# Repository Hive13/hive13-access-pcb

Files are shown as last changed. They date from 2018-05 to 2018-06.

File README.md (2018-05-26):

# hive13-access-pcb
KiCad files for the circuit board that controls doors.

## Board Design
This board is designed so that it can be sent to a fab house and done dual-layer, or milled with a CNC, single-sided, and done in the "jumper links" style.
This results in several constraints:
- The top-side PCB traces need to both be in a straight line and not cross over any top-side components.
- All surface-mount components need to be on the bottom layer.
- No vias under bottom-side components.
- Assume that there will be no bottom-side solder mask.  Take this into account when running traces under a bottom-side component.

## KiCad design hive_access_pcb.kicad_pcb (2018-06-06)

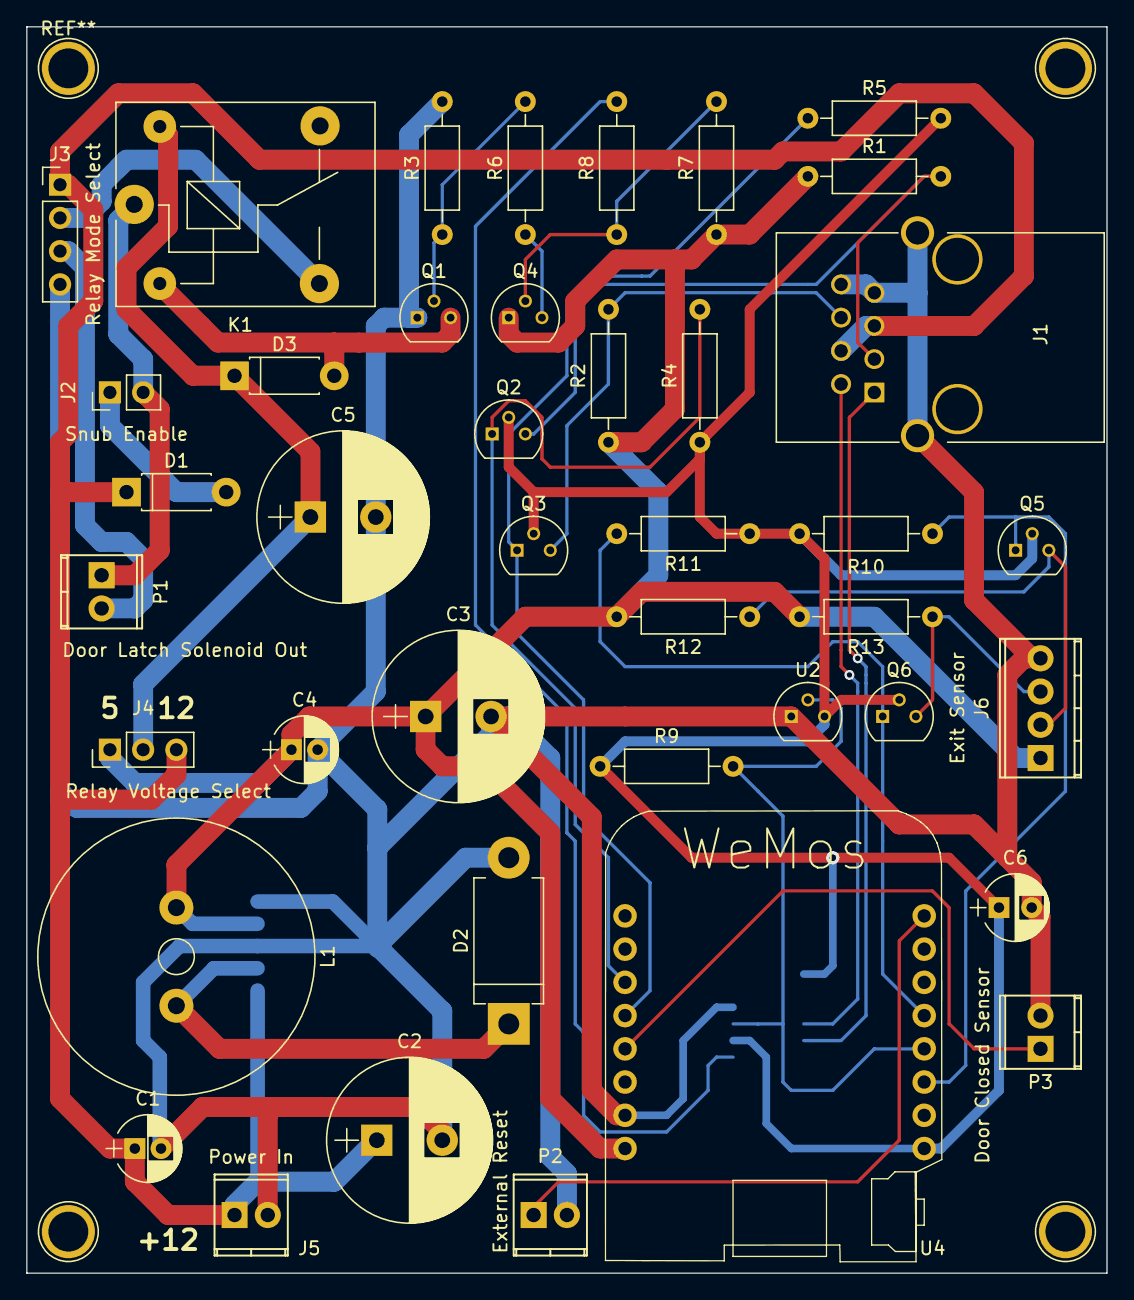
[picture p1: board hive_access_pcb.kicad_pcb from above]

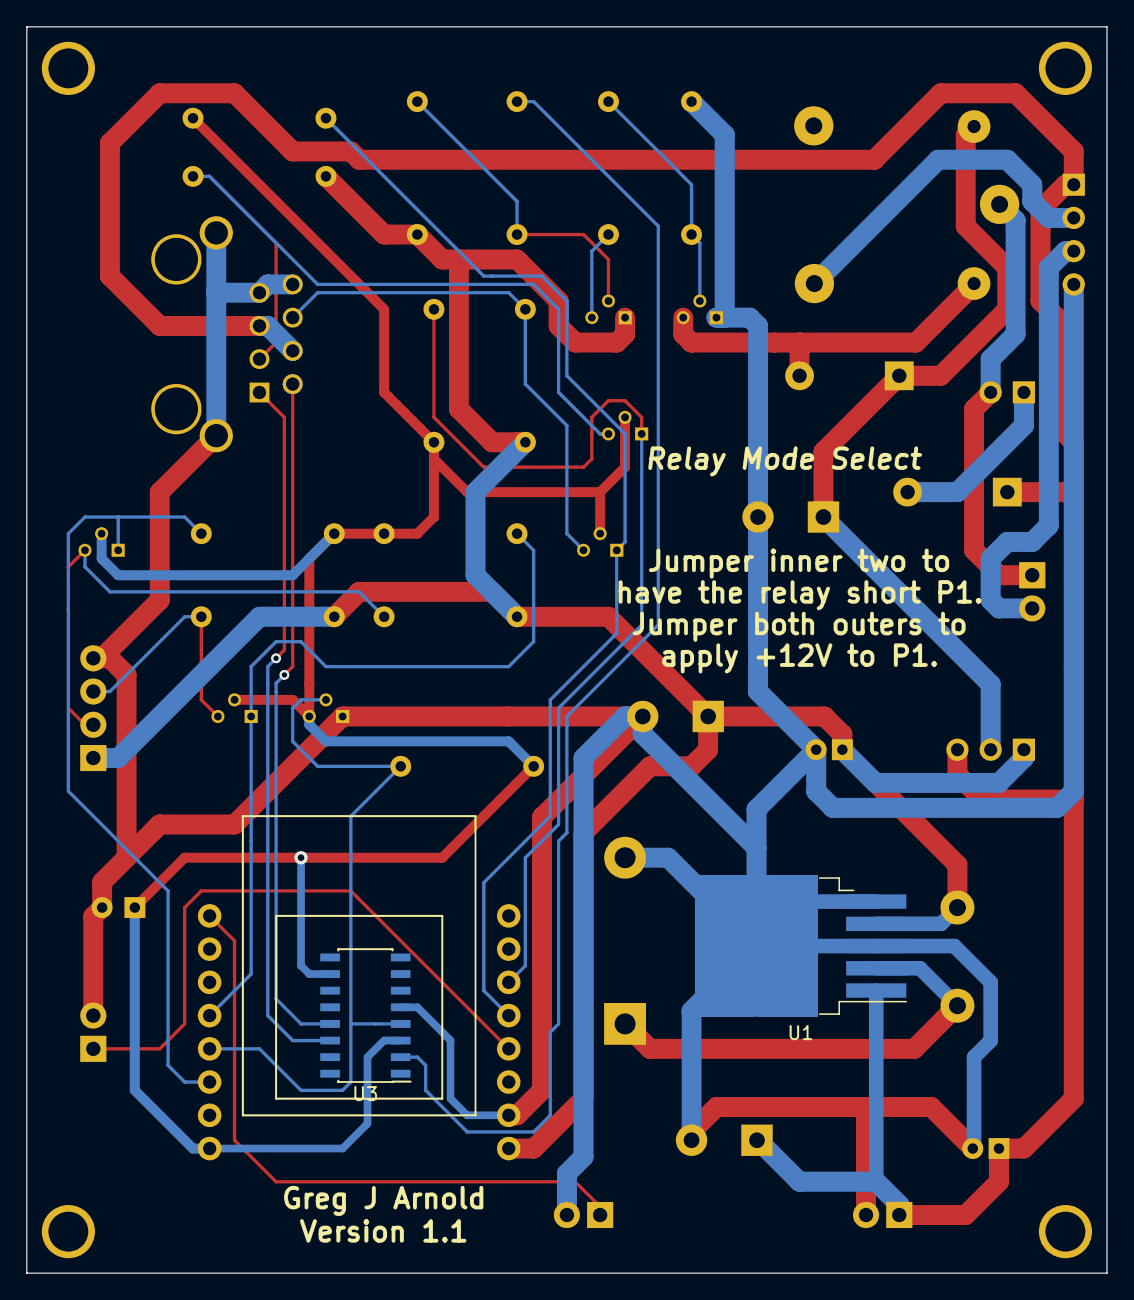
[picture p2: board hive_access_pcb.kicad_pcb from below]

Board: 2 copper layers, 82.6 x 95.2 mm, 43 parts (2 on the bottom side), 28 nets.

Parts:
C1, C4: 1MFD; CP_Radial_D5.0mm_P2.00mm
C2: 100MFD; CP_Radial_D12.5mm_P5.00mm
C3, C5: 1000MFD; CP_Radial_D13.0mm_P5.00mm
C6: 1MFD; CP_Radial_D5.0mm_P2.50mm
D1, D3: 1N4002; D_DO-41_SOD81_P7.62mm_Horizontal
D2: D_Schottky; D_DO-201AD_P12.70mm_Horizontal
J1: Door Reader; RJ45_SHIELD
J2: Snub Enable; Pin_Header_Straight_1x02_Pitch2.54mm
J3: Relay Mode Select; Pin_Header_Straight_1x04_Pitch2.54mm
J4: Relay Voltage Select; Pin_Header_Straight_1x03_Pitch2.54mm
J5: Power In; TerminalBlock_Pheonix_MPT-2.54mm_2pol
J6: Exit Sensor; TerminalBlock_Pheonix_MPT-2.54mm_4pol
K1: SANYOU_SRD_Form_C; Relay_SPDT_SANYOU_SRD_Series_Form_C
L1: L; L_Radial_D21.0mm_P7.5mm
P1: Door Latch Solenoid Out; TerminalBlock_Pheonix_MPT-2.54mm_2pol
P2: External Reset; TerminalBlock_Pheonix_MPT-2.54mm_2pol
P3: Door Closed Sensor; TerminalBlock_Pheonix_MPT-2.54mm_2pol
Q1: 2N2222; TO-92_Molded_Narrow
Q2, Q3, Q5, Q6: 2N7000; TO-92_Molded_Narrow
Q4: 2N3906; TO-92_Molded_Narrow
R1, R2, R3, R4, R5, R7, R10, R11, R12, R13: 10kΩ; R_Axial_DIN0207_L6.3mm_D2.5mm_P10.16mm_Horizontal
R6: 1.2kΩ; R_Axial_DIN0207_L6.3mm_D2.5mm_P10.16mm_Horizontal
R8: 1kΩ; R_Axial_DIN0207_L6.3mm_D2.5mm_P10.16mm_Horizontal
R9: 4.7kΩ; R_Axial_DIN0207_L6.3mm_D2.5mm_P10.16mm_Horizontal
U1: LM2576S-5; TO-263-5_TabPin3
U2: DS18B20; TO-92_Molded_Narrow
U3: DS2408; SOIC-16_3.9x9.9mm_Pitch1.27mm
U4: WeMos_mini; D1_mini_board

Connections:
+3V3: C6.1, Q2.2, Q3.2, Q5.2, Q6.2, R4.1, R5.2, R9.1, R10.2, R11.1, U2.3, U3.3, U3.10, U4.16
+5V: C3.1, C4.1, J4.1, J6.1, L1.1, Q4.1, R1.1, R2.1, R7.1, R12.2, R13.2, U1.4, U4.1
+12V: C1.1, C2.1, D1.1, J1.4, J1.5, J3.1, J4.3, J5.1, U1.1
/BASE_DOOR: Q1.2, R3.1, R6.2
/BASE_DOOR_2: Q4.2, R7.2, R8.1
/CONN_CONTACT: J3.3, P1.2
/DOOR_OPEN: R8.2, U3.2
/DOOR_SENSOR: P3.1, U4.4
/HC_ECHO: J6.3, Q6.3, R13.1
/HC_TRIG: J6.2, Q5.3, R12.1
/ONE_WIRE: R9.2, U2.2, U3.4, U4.13
/RELAY_CONN: J2.2, K1.1, P1.1
/RELAY_CONTACT: J3.2, K1.3
/RELAY_DOOR: D3.2, K1.2, Q1.3
/RELAY_POWER: C5.1, D3.1, J4.2, K1.5
/VREG_OUT: D2.1, L1.2, U1.2
/WEMOS_D0: Q3.1, R5.1, U4.5
/WEMOS_D1: Q2.1, R4.2, U4.6
/WEMOS_ECHO: Q6.1, R11.2, U4.12
/WEMOS_TRIG: Q5.1, R10.1, U4.14
/WIEGAND_BEEP: J1.1, U3.14
/WIEGAND_D0: J1.6, Q3.3, R2.2
/WIEGAND_D1: J1.3, Q2.3, R1.2
/WIEGAND_LIGHT: J1.2, U3.13
/~RST: P2.1, U4.9
GND: C1.2, C2.2, C3.2, C4.2, C5.2, C6.2, D2.2, J1.7, J1.8, J1.9, J3.4, J5.2, J6.4, P2.2, P3.2, Q1.1, R3.2, U1.3, U1.5, U2.1, U3.5, U4.2
unnamed: D1.2, J2.1
unnamed: Q4.3, R6.1

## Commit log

2018-05-26 Update README.md
    Add in design style of the board.
2018-05-26 First check-in of schematic.
    [hive_access_pcb.kicad_pcb, hive_access_pcb.sch]
2018-05-26 First draft of the schematic.
    [hive_access_pcb.sch]
2018-05-27 Assigned all components to provisional footprints, started organizing PCB layout.
    [hive_access_pcb.kicad_pcb, hive_access_pcb.sch]
2018-05-27 All components correctly sized, except connectors. Need to check TO-92 pinouts.
    [hive_access_pcb.kicad_pcb, hive_access_pcb.sch]
2018-05-28 First draft of the circuit board.
    [hive_access_pcb.kicad_pcb, hive_access_pcb.sch]
2018-05-28 Design rule tweaks.
    [hive_access_pcb.kicad_pcb]
2018-05-28 Rename the single-sided board.
2018-05-28 Grouping components for 2-sided.
    [hive_access_pcb.kicad_pcb]
2018-05-28 Basic layout.
    [hive_access_pcb.kicad_pcb]
2018-05-28 First draft of actual PCB.
    [hive_access_pcb.kicad_pcb]
2018-06-06 Fix issues.
    [hive_access_pcb.kicad_pcb, hive_access_pcb.sch]
